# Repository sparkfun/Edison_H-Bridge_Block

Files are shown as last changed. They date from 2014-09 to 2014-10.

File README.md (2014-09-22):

Dual H-bridge
=====================

The Dual H-bridge give the Edison some ability to move when paired with two DC motors.  This board can drive two DC motors at voltages ranging from 2.7V-15V and currents up to 1amp.  This board is isolated from the Edison using a logic level converter.  To use this board external power for the motors will be required.  Power for the motors is supplied on the headers labled "VIN" and "GND"

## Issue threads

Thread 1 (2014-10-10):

TBx0108 max voltage on "B" side... or breaking out "VM" for higher voltages

lewispg228, 2014-10-10:
I think it might be worth noting that the max voltage you can supply on VIN is 5.5V, or else you are going outside the max voltage on the "B" side of the logic conversion chip.

I was working on the testbed for this, and was worried that 5.5V may only light up the LEDs very dimly (a pain to test visually in production). We could think about reducing the values for R1 and R2, or we could think about breaking out VM, to allow for higher voltages to your motors (while still keeping the logic level within the TBX0108 chips specs)

ToniCorinne, 2016-07-19:
Closing out this issue as there do not appear to be any customer complaints about this currently.

Closed 2016-07-19.

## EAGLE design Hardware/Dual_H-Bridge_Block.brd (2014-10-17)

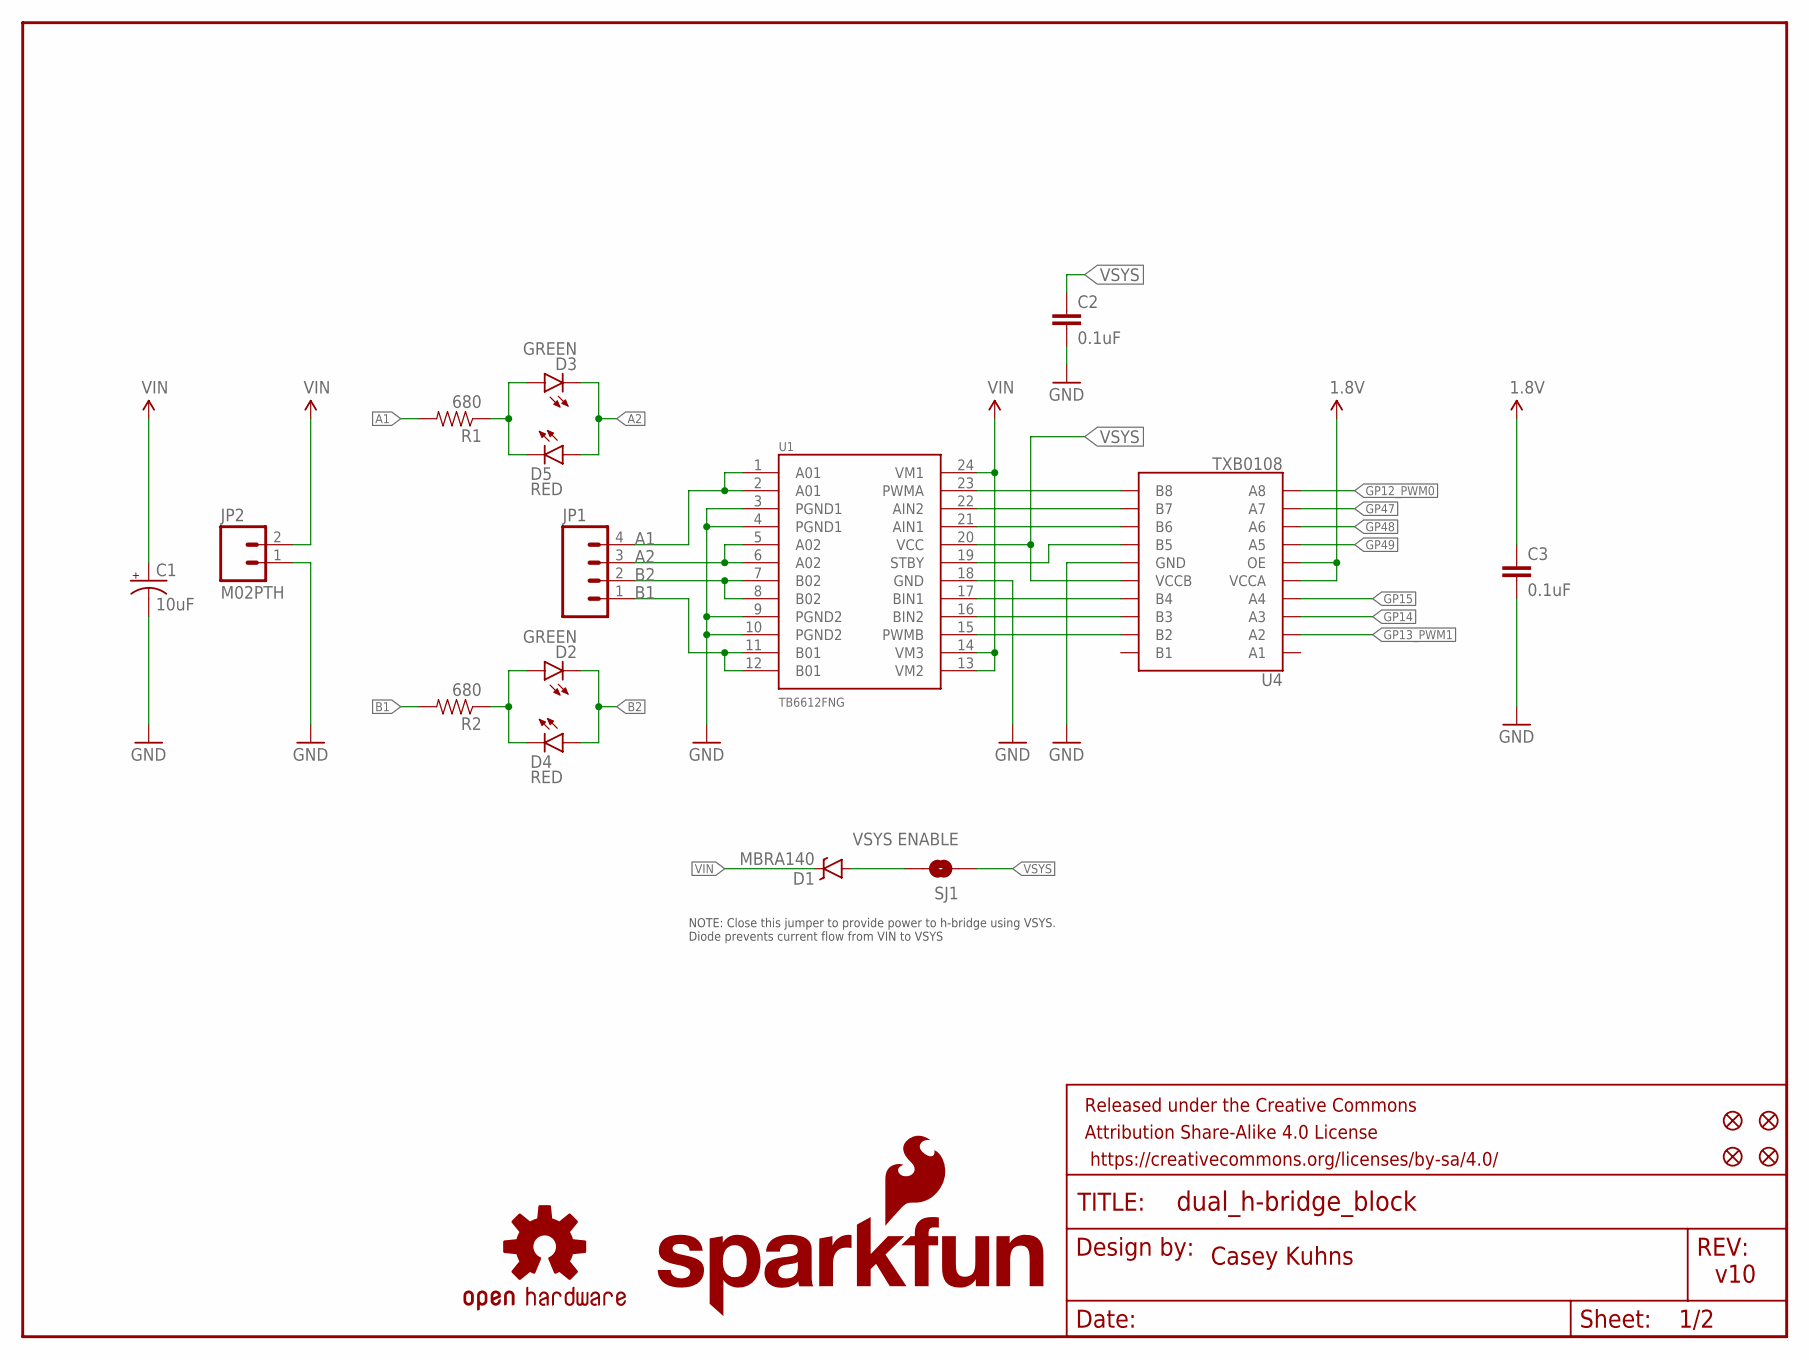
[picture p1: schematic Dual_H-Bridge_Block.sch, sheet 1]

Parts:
C1: 10uF; EIA3216
C2, C3: 0.1uF; 0603-CAP
D1: MBRA140; SMA-DIODE
D2, D3: GREEN; LED-0603
D4, D5: RED; LED-0603
FID1, FID2, FID3, FID4: FIDUCIAL1X2; FIDUCIAL-1X2
FRAME1: FRAME-LETTER; CREATIVE_COMMONS
JP1: M04PTH; 1X04
JP2: M02PTH; 1X02
LOGO1: OSHW-LOGOS; OSHW-LOGO-S
LOGO4: SFE_LOGO_NAME_FLAME.1_INCH; SFE_LOGO_NAME_FLAME_.1
R1, R2: 680; 0603-RES
SJ1: VSYS ENABLE; PAD-JUMPER-2-NO_YES_SILK
U1: TB6612FNG; SSOP24
U4: TXB0108; UFDFN-20

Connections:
1.8V: C3.1, U4.5 (VCCA), U4.6 (OE); also elsewhere on the board
A1: JP1.4, R1.2, U1.1 (A01), U1.2 (A01)
A2: D3.C, D5.A, JP1.3, U1.5 (A02), U1.6 (A02)
B1: JP1.1, R2.2, U1.11 (B01), U1.12 (B01)
B2: D2.C, D4.A, JP1.2, U1.7 (B02), U1.8 (B02)
GND: C1.C (-), C2.2, C3.2, JP2.1, U1.3 (PGND1), U1.4 (PGND1), U1.9 (PGND2), U1.10 (PGND2), U1.18 (GND), U4.15 (GND); also elsewhere on the board
GP12_PWM0: U4.10 (A8); also elsewhere on the board
GP13_PWM1: U4.2 (A2); also elsewhere on the board
GP14: U4.3 (A3); also elsewhere on the board
GP15: U4.4 (A4); also elsewhere on the board
GP47: U4.9 (A7); also elsewhere on the board
GP48: U4.8 (A6); also elsewhere on the board
GP49: U4.7 (A5); also elsewhere on the board
unnamed: D1.A, SJ1.2
unnamed: D2.A, D4.C, R2.1
unnamed: U1.15 (PWMB), U4.19 (B2)
unnamed: U1.23 (PWMA), U4.11 (B8)
unnamed: D3.A, D5.C, R1.1
unnamed: U1.19 (STBY), U4.14 (B5)
unnamed: U1.17 (BIN1), U4.17 (B4)
unnamed: U1.16 (BIN2), U4.18 (B3)
unnamed: U1.21 (AIN1), U4.13 (B6)
unnamed: U1.22 (AIN2), U4.12 (B7)
VIN: C1.A (+), D1.C, JP2.2, U1.13 (VM2), U1.14 (VM3), U1.24 (VM1)
VSYS: C2.1, SJ1.1, U1.20 (VCC), U4.16 (VCCB); also elsewhere on the board

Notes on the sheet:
v10
Casey Kuhns
NOTE: Close this jumper to provide power to h-bridge using VSYS. Diode prevents current flow from VIN to VSYS

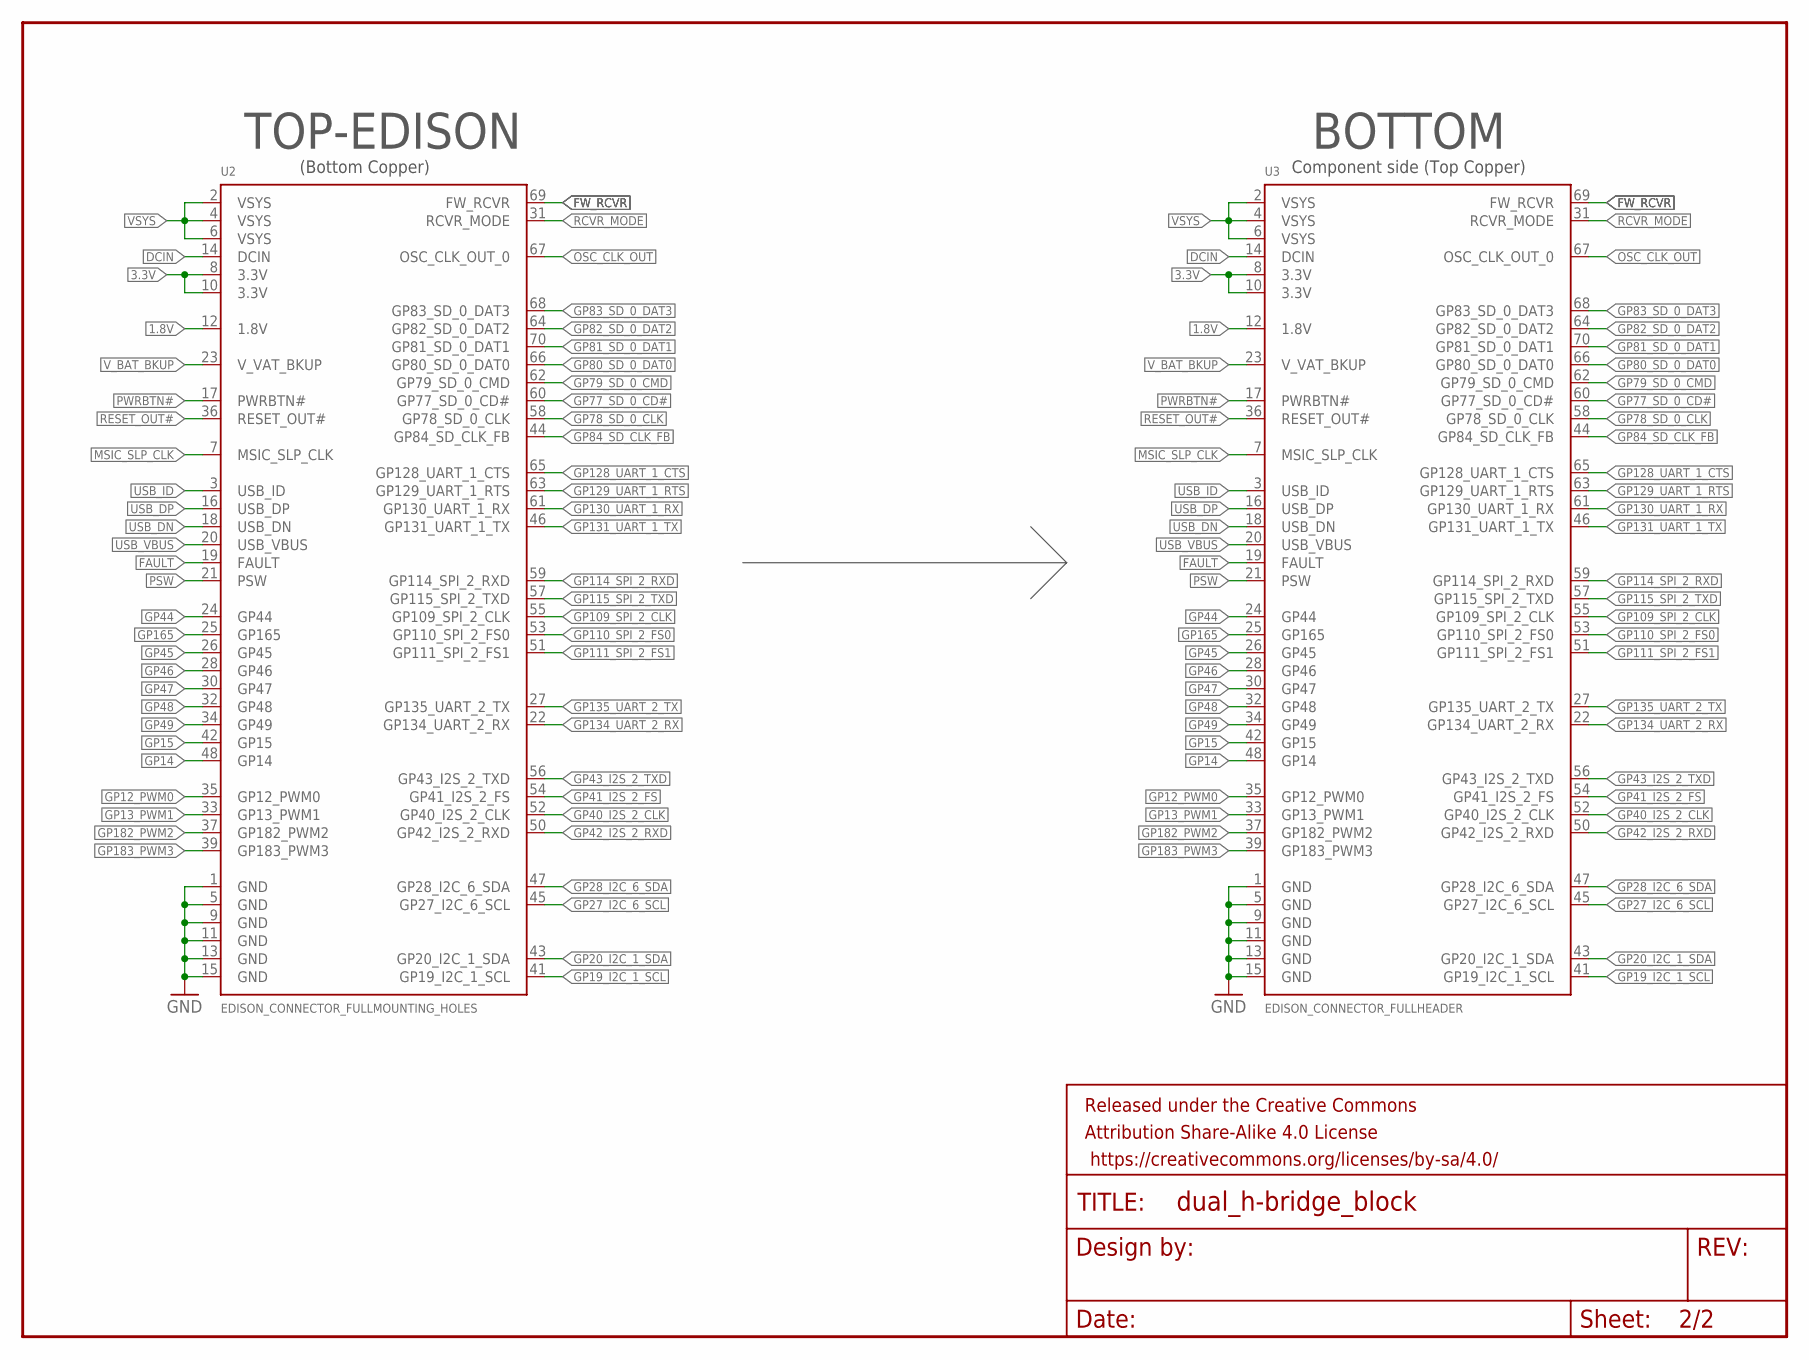
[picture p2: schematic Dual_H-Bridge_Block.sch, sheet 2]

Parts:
FRAME2: FRAME-LETTER; CREATIVE_COMMONS
U2: EDISON_CONNECTOR_FULLMOUNTING_HOLES; EDISON_DAUGHTER
U3: EDISON_CONNECTOR_FULLHEADER; DF40C-70DP-0.4(51)

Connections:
1.8V: U2.12 (1.8V), U3.12 (1.8V); also elsewhere on the board
3.3V: U2.8 (3.3V), U2.10 (3.3V), U3.8 (3.3V), U3.10 (3.3V)
DCIN: U2.14 (DCIN), U3.14 (DCIN)
FAULT: U2.19 (FAULT), U3.19 (FAULT)
FW_RCVR: U2.69 (FW_RCVR), U3.69 (FW_RCVR)
GND: U2.1 (GND), U2.5 (GND), U2.9 (GND), U2.11 (GND), U2.13 (GND), U2.15 (GND), U3.1 (GND), U3.5 (GND), U3.9 (GND), U3.11 (GND), U3.13 (GND), U3.15 (GND); also elsewhere on the board
GP12_PWM0: U2.35 (GP12_PWM0), U3.35 (GP12_PWM0); also elsewhere on the board
GP13_PWM1: U2.33 (GP13_PWM1), U3.33 (GP13_PWM1); also elsewhere on the board
GP14: U2.48 (GP14), U3.48 (GP14); also elsewhere on the board
GP15: U2.42 (GP15), U3.42 (GP15); also elsewhere on the board
GP19_I2C_1_SCL: U2.41 (GP19_I2C_1_SCL), U3.41 (GP19_I2C_1_SCL)
GP20_I2C_1_SDA: U2.43 (GP20_I2C_1_SDA), U3.43 (GP20_I2C_1_SDA)
GP27_I2C_6_SCL: U2.45 (GP27_I2C_6_SCL), U3.45 (GP27_I2C_6_SCL)
GP28_I2C_6_SDA: U2.47 (GP28_I2C_6_SDA), U3.47 (GP28_I2C_6_SDA)
GP40_I2S_2_CLK: U2.52 (GP40_I2S_2_CLK), U3.52 (GP40_I2S_2_CLK)
GP41_I2S_2_FS: U2.54 (GP41_I2S_2_FS), U3.54 (GP41_I2S_2_FS)
GP42_I2S_2_RXD: U2.50 (GP42_I2S_2_RXD), U3.50 (GP42_I2S_2_RXD)
GP43_I2S_2_TXD: U2.56 (GP43_I2S_2_TXD), U3.56 (GP43_I2S_2_TXD)
GP44: U2.24 (GP44), U3.24 (GP44)
GP45: U2.26 (GP45), U3.26 (GP45)
GP46: U2.28 (GP46), U3.28 (GP46)
GP47: U2.30 (GP47), U3.30 (GP47); also elsewhere on the board
GP48: U2.32 (GP48), U3.32 (GP48); also elsewhere on the board
GP49: U2.34 (GP49), U3.34 (GP49); also elsewhere on the board
GP77_SD_0_CD#: U2.60 (GP77_SD_0_CD#), U3.60 (GP77_SD_0_CD#)
GP78_SD_0_CLK: U2.58 (GP78_SD_0_CLK), U3.58 (GP78_SD_0_CLK)
GP79_SD_0_CMD: U2.62 (GP79_SD_0_CMD), U3.62 (GP79_SD_0_CMD)
GP80_SD_0_DAT0: U2.66 (GP80_SD_0_DAT0), U3.66 (GP80_SD_0_DAT0)
GP81_SD_0_DAT1: U2.70 (GP81_SD_0_DAT1), U3.70 (GP81_SD_0_DAT1)
GP82_SD_0_DAT2: U2.64 (GP82_SD_0_DAT2), U3.64 (GP82_SD_0_DAT2)
GP83_SD_0_DAT3: U2.68 (GP83_SD_0_DAT3), U3.68 (GP83_SD_0_DAT3)
GP84_SD_CLK_FB: U2.44 (GP84_SD_CLK_FB), U3.44 (GP84_SD_CLK_FB)
GP109_SPI_2_CLK: U2.55 (GP109_SPI_2_CLK), U3.55 (GP109_SPI_2_CLK)
GP110_SPI_2_FS0: U2.53 (GP110_SPI_2_FS0), U3.53 (GP110_SPI_2_FS0)
GP111_SPI_2_FS1: U2.51 (GP111_SPI_2_FS1), U3.51 (GP111_SPI_2_FS1)
GP114_SPI_2_RXD: U2.59 (GP114_SPI_2_RXD), U3.59 (GP114_SPI_2_RXD)
GP115_SPI_2_TXD: U2.57 (GP115_SPI_2_TXD), U3.57 (GP115_SPI_2_TXD)
GP128_UART_1_CTS: U2.65 (GP128_UART_1_CTS), U3.65 (GP128_UART_1_CTS)
GP129_UART_1_RTS: U2.63 (GP129_UART_1_RTS), U3.63 (GP129_UART_1_RTS)
GP130_UART_1_RX: U2.61 (GP130_UART_1_RX), U3.61 (GP130_UART_1_RX)
GP131_UART_1_TX: U2.46 (GP131_UART_1_TX), U3.46 (GP131_UART_1_TX)
GP134_UART_2_RX: U2.22 (GP134_UART_2_RX), U3.22 (GP134_UART_2_RX)
GP135_UART_2_TX: U2.27 (GP135_UART_2_TX), U3.27 (GP135_UART_2_TX)
GP165: U2.25 (GP165), U3.25 (GP165)
GP182_PWM2: U2.37 (GP182_PWM2), U3.37 (GP182_PWM2)
GP183_PWM3: U2.39 (GP183_PWM3), U3.39 (GP183_PWM3)
MSIC_SLP_CLK: U2.7 (MSIC_SLP_CLK), U3.7 (MSIC_SLP_CLK)
OSC_CLK_OUT: U2.67 (OSC_CLK_OUT_0), U3.67 (OSC_CLK_OUT_0)
PSW: U2.21 (PSW), U3.21 (PSW)
PWRBTN#: U2.17 (PWRBTN#), U3.17 (PWRBTN#)
RCVR_MODE: U2.31 (RCVR_MODE), U3.31 (RCVR_MODE)
RESET_OUT#: U2.36 (RESET_OUT#), U3.36 (RESET_OUT#)
USB_DN: U2.18 (USB_DN), U3.18 (USB_DN)
USB_DP: U2.16 (USB_DP), U3.16 (USB_DP)
USB_ID: U2.3 (USB_ID), U3.3 (USB_ID)
USB_VBUS: U2.20 (USB_VBUS), U3.20 (USB_VBUS)
VSYS: U2.2 (VSYS), U2.4 (VSYS), U2.6 (VSYS), U3.2 (VSYS), U3.4 (VSYS), U3.6 (VSYS); also elsewhere on the board
V_BAT_BKUP: U2.23 (V_VAT_BKUP), U3.23 (V_VAT_BKUP)

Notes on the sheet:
TOP-EDISON
BOTTOM
Component side (Top Copper)
(Bottom Copper)

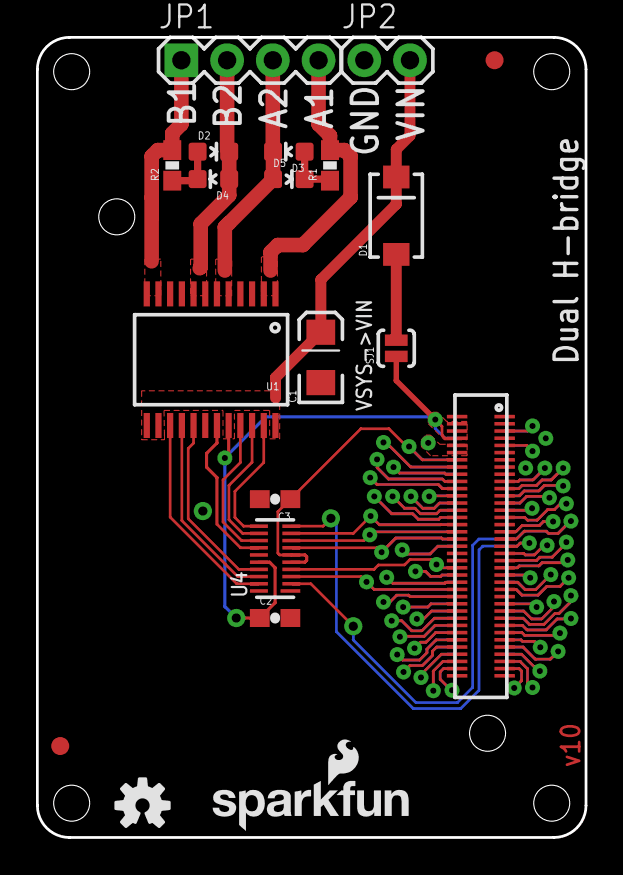
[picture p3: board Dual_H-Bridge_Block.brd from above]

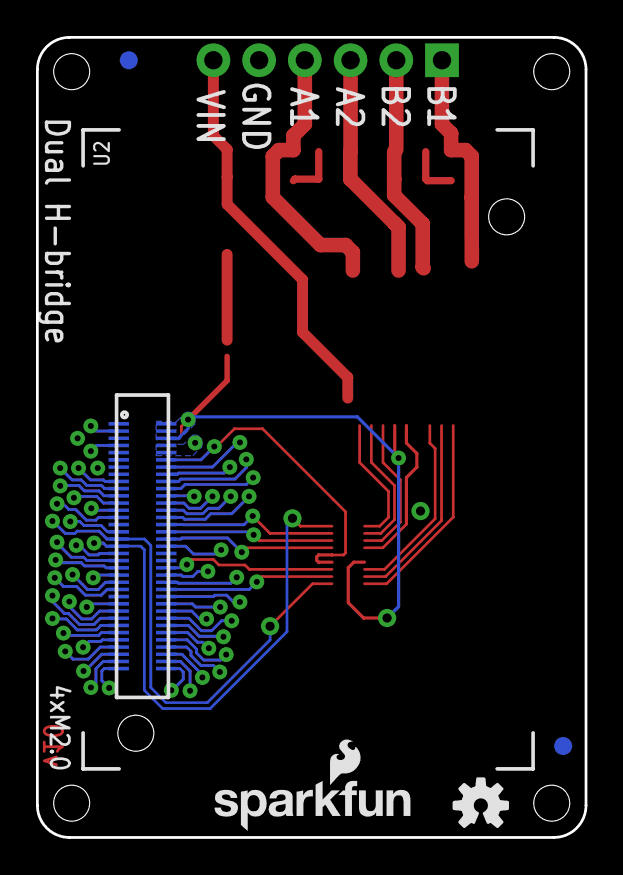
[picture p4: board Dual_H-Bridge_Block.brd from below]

Board: 2 copper layers, 30.5 x 44.5 mm, 27 parts (6 on the bottom side), 73 nets.

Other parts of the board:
LOGO2: OSHW-LOGOS; OSHW-LOGO-S
LOGO3: SFE_LOGO_NAME_FLAME.1_INCH; SFE_LOGO_NAME_FLAME_.1

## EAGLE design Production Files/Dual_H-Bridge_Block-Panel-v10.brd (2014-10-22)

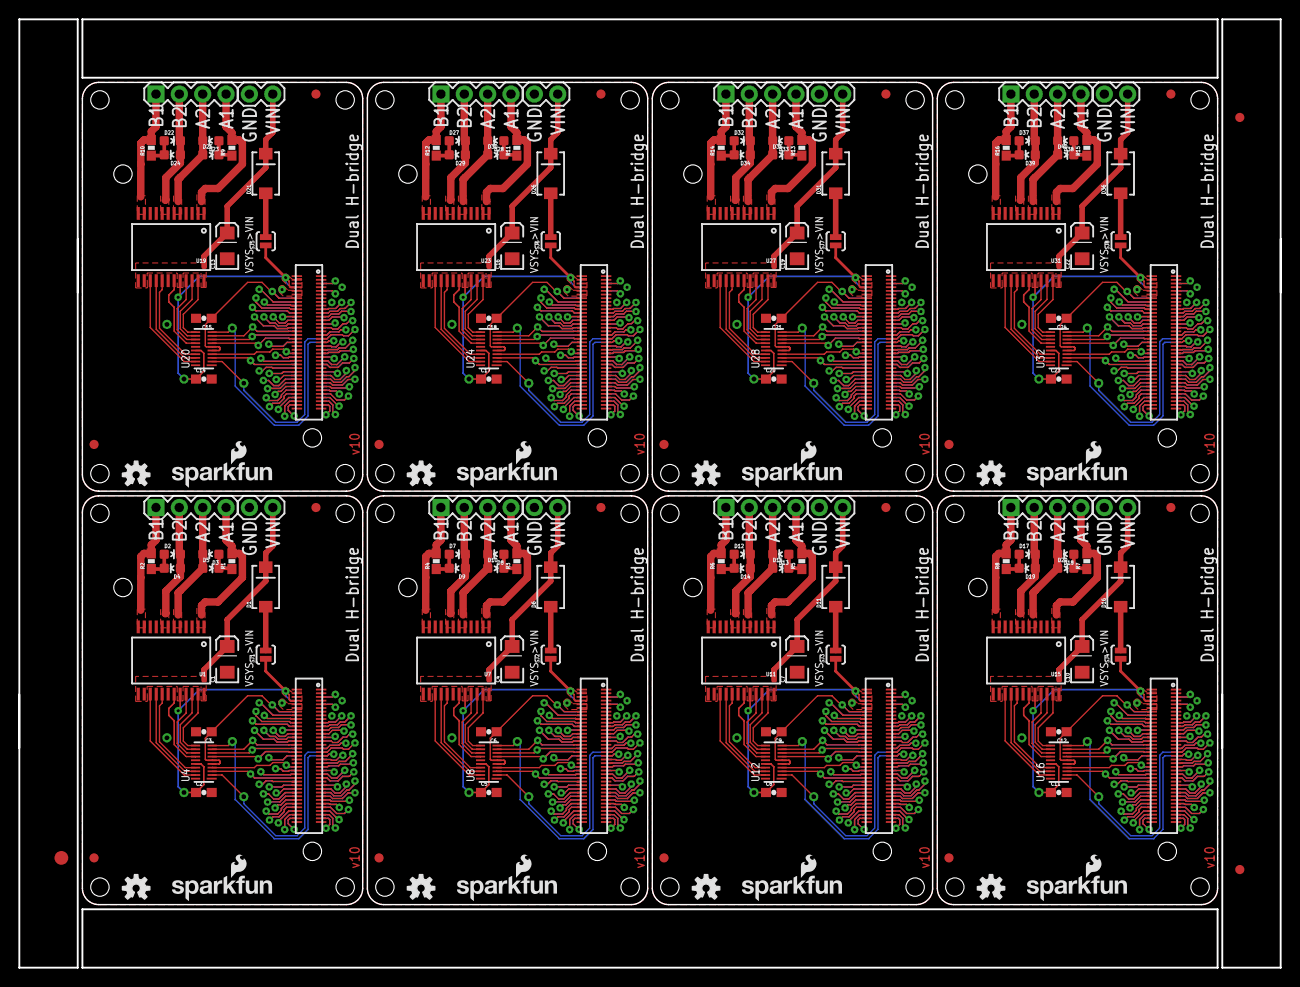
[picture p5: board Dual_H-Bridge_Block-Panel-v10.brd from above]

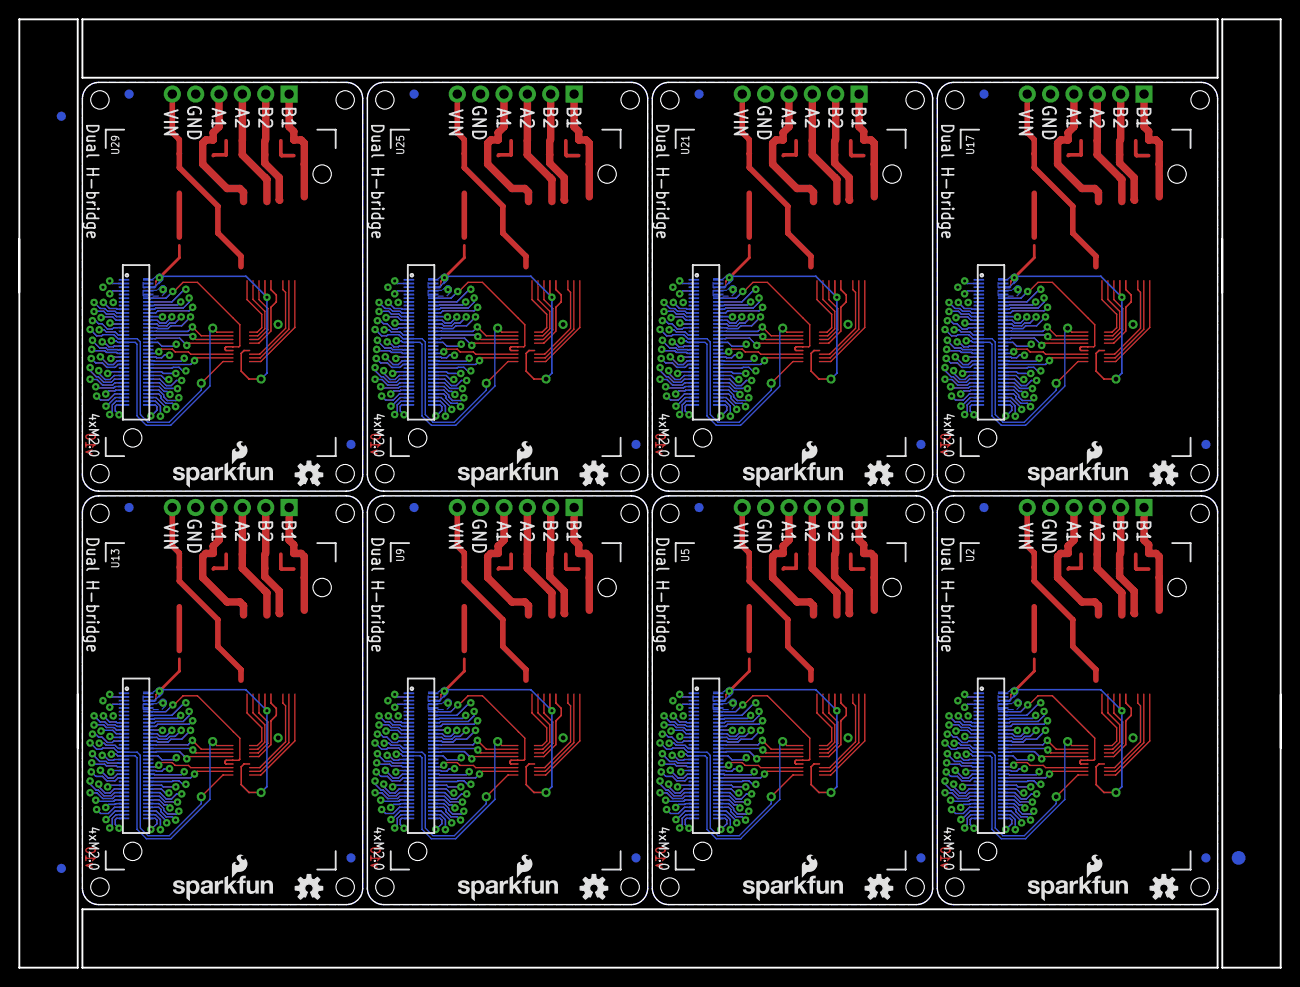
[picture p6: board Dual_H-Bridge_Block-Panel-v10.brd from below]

Board: 2 copper layers, 137.2 x 103.1 mm, 206 parts (51 on the bottom side), 584 nets.

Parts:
C1, C4, C7, C10, C13, C16, C19, C22: 10uF; EIA3216
C2, C3, C5, C6, C8, C9, C11, C12, C14, C15, C17, C18, C20, C21, C23, C24: 0.1uF; 0603-CAP
D1, D6, D11, D16, D21, D26, D31, D36: MBRA140; SMA-DIODE
D2, D3, D7, D8, D12, D13, D17, D18, D22, D23, D27, D28, D32, D33, D37, D38: GREEN; LED-0603
D4, D5, D9, D10, D14, D15, D19, D20, D24, D25, D29, D30, D34, D35, D39, D40: RED; LED-0603
E$1, E$2: FIDUCIAL-1.5X3
E$3, E$4, E$5, E$6: FIDUCIAL-1X2
FID1, FID2, FID3, FID4, FID5, FID6, FID7, FID8, FID9, FID10, FID11, FID12, FID13, FID14, FID15, FID16, FID17, FID18, FID19, FID20, FID21, FID22, FID23, FID24, FID25, FID26, FID27, FID28, FID29, FID30, FID31, FID32: FIDUCIAL1X2; FIDUCIAL-1X2
JP1, JP3, JP5, JP7, JP9, JP11, JP13, JP15: 1X04
JP2, JP4, JP6, JP8, JP10, JP12, JP14, JP16: M02PTH; 1X02
LOGO1, LOGO2, LOGO5, LOGO7, LOGO9, LOGO11, LOGO13, LOGO15, LOGO17, LOGO19, LOGO21, LOGO23, LOGO25, LOGO27, LOGO29, LOGO31: OSHW-LOGOS; OSHW-LOGO-S
LOGO3, LOGO4, LOGO6, LOGO8, LOGO10, LOGO12, LOGO14, LOGO16, LOGO18, LOGO20, LOGO22, LOGO24, LOGO26, LOGO28, LOGO30, LOGO32: SFE_LOGO_NAME_FLAME.1_INCH; SFE_LOGO_NAME_FLAME_.1
R1, R2, R3, R4, R5, R6, R7, R8, R9, R10, R11, R12, R13, R14, R15, R16: 680; 0603-RES
SJ1, SJ2, SJ3, SJ4, SJ5, SJ6, SJ7, SJ8: VSYS ENABLE; PAD-JUMPER-2-NO_YES_SILK
U1, U7, U11, U15, U19, U23, U27, U31: TB6612FNG; SSOP24
U2, U5, U9, U13, U17, U21, U25, U29: EDISON_CONNECTOR_FULLMOUNTING_HOLES; EDISON_DAUGHTER
U3, U6, U10, U14, U18, U22, U26, U30: EDISON_CONNECTOR_FULLHEADER; DF40C-70DP-0.4(51)
U4, U8, U12, U16, U20, U24, U28, U32: TXB0108; UFDFN-20

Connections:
1.8V: C3.1, U2.12, U3.12, U4.5, U4.6
1.8V1: C6.1, U5.12, U6.12, U8.5, U8.6
1.8V2: C9.1, U9.12, U10.12, U12.5, U12.6
1.8V3: C12.1, U13.12, U14.12, U16.5, U16.6
1.8V4: C15.1, U17.12, U18.12, U20.5, U20.6
1.8V5: C18.1, U21.12, U22.12, U24.5, U24.6
1.8V6: C21.1, U25.12, U26.12, U28.5, U28.6
1.8V7: C24.1, U29.12, U30.12, U32.5, U32.6
3.3V: U2.8, U2.10, U3.8, U3.10
3.3V1: U5.8, U5.10, U6.8, U6.10
3.3V2: U9.8, U9.10, U10.8, U10.10
3.3V3: U13.8, U13.10, U14.8, U14.10
3.3V4: U17.8, U17.10, U18.8, U18.10
3.3V5: U21.8, U21.10, U22.8, U22.10
3.3V6: U25.8, U25.10, U26.8, U26.10
3.3V7: U29.8, U29.10, U30.8, U30.10
A1: JP1.4, R1.2, U1.1, U1.2
A2: D3.C, D5.A, JP1.3, U1.5, U1.6
A3: D8.C, D10.A, JP3.3, U7.5, U7.6
A4: JP3.4, R3.2, U7.1, U7.2
A5: D13.C, D15.A, JP5.3, U11.5, U11.6
A6: JP5.4, R5.2, U11.1, U11.2
A7: D18.C, D20.A, JP7.3, U15.5, U15.6
A8: JP7.4, R7.2, U15.1, U15.2
A9: D23.C, D25.A, JP9.3, U19.5, U19.6
A10: JP9.4, R9.2, U19.1, U19.2
A11: D28.C, D30.A, JP11.3, U23.5, U23.6
A12: JP11.4, R11.2, U23.1, U23.2
A13: D33.C, D35.A, JP13.3, U27.5, U27.6
A14: JP13.4, R13.2, U27.1, U27.2
A15: D38.C, D40.A, JP15.3, U31.5, U31.6
A16: JP15.4, R15.2, U31.1, U31.2
B1: JP1.1, R2.2, U1.11, U1.12
B2: D2.C, D4.A, JP1.2, U1.7, U1.8
B3: JP3.1, R4.2, U7.11, U7.12
B4: D7.C, D9.A, JP3.2, U7.7, U7.8
B5: JP5.1, R6.2, U11.11, U11.12
B6: D12.C, D14.A, JP5.2, U11.7, U11.8
B7: JP7.1, R8.2, U15.11, U15.12
B8: D17.C, D19.A, JP7.2, U15.7, U15.8
B9: JP9.1, R10.2, U19.11, U19.12
B10: D22.C, D24.A, JP9.2, U19.7, U19.8
B11: JP11.1, R12.2, U23.11, U23.12
B12: D27.C, D29.A, JP11.2, U23.7, U23.8
B13: JP13.1, R14.2, U27.11, U27.12
B14: D32.C, D34.A, JP13.2, U27.7, U27.8
B15: JP15.1, R16.2, U31.11, U31.12
B16: D37.C, D39.A, JP15.2, U31.7, U31.8
DCIN: U2.14, U3.14
DCIN1: U5.14, U6.14
DCIN2: U9.14, U10.14
DCIN3: U13.14, U14.14
DCIN4: U17.14, U18.14
DCIN5: U21.14, U22.14
DCIN6: U25.14, U26.14
DCIN7: U29.14, U30.14
FAULT: U2.19, U3.19
FAULT1: U5.19, U6.19
FAULT2: U9.19, U10.19
FAULT3: U13.19, U14.19
FAULT4: U17.19, U18.19
FAULT5: U21.19, U22.19
FAULT6: U25.19, U26.19
FAULT7: U29.19, U30.19
FW_RCVR: U2.69, U3.69
FW_RCVR1: U5.69, U6.69
FW_RCVR2: U9.69, U10.69
FW_RCVR3: U13.69, U14.69
FW_RCVR4: U17.69, U18.69
FW_RCVR5: U21.69, U22.69
FW_RCVR6: U25.69, U26.69
FW_RCVR7: U29.69, U30.69
GND: C1.C, C2.2, C3.2, JP2.1, U1.3, U1.4, U1.9, U1.10, U1.18, U2.1, U2.5, U2.9, U2.11, U2.13, U2.15, U3.1, U3.5, U3.9, U3.11, U3.13, U3.15, U4.15
GND1: C4.C, C5.2, C6.2, JP4.1, U5.1, U5.5, U5.9, U5.11, U5.13, U5.15, U6.1, U6.5, U6.9, U6.11, U6.13, U6.15, U7.3, U7.4, U7.9, U7.10, U7.18, U8.15
GND2: C7.C, C8.2, C9.2, JP6.1, U9.1, U9.5, U9.9, U9.11, U9.13, U9.15, U10.1, U10.5, U10.9, U10.11, U10.13, U10.15, U11.3, U11.4, U11.9, U11.10, U11.18, U12.15
GND3: C10.C, C11.2, C12.2, JP8.1, U13.1, U13.5, U13.9, U13.11, U13.13, U13.15, U14.1, U14.5, U14.9, U14.11, U14.13, U14.15, U15.3, U15.4, U15.9, U15.10, U15.18, U16.15
GND4: C13.C, C14.2, C15.2, JP10.1, U17.1, U17.5, U17.9, U17.11, U17.13, U17.15, U18.1, U18.5, U18.9, U18.11, U18.13, U18.15, U19.3, U19.4, U19.9, U19.10, U19.18, U20.15
GND5: C16.C, C17.2, C18.2, JP12.1, U21.1, U21.5, U21.9, U21.11, U21.13, U21.15, U22.1, U22.5, U22.9, U22.11, U22.13, U22.15, U23.3, U23.4, U23.9, U23.10, U23.18, U24.15
GND6: C19.C, C20.2, C21.2, JP14.1, U25.1, U25.5, U25.9, U25.11, U25.13, U25.15, U26.1, U26.5, U26.9, U26.11, U26.13, U26.15, U27.3, U27.4, U27.9, U27.10, U27.18, U28.15
GND7: C22.C, C23.2, C24.2, JP16.1, U29.1, U29.5, U29.9, U29.11, U29.13, U29.15, U30.1, U30.5, U30.9, U30.11, U30.13, U30.15, U31.3, U31.4, U31.9, U31.10, U31.18, U32.15
GP1: U5.48, U6.48, U8.3
GP2: U5.42, U6.42, U8.4
GP3: U5.34, U6.34, U8.7
GP4: U5.32, U6.32, U8.8
GP5: U5.30, U6.30, U8.9
GP6: U5.28, U6.28
GP7: U5.26, U6.26
GP8: U5.25, U6.25
GP9: U5.24, U6.24
GP10: U9.48, U10.48, U12.3
GP11: U9.42, U10.42, U12.4
GP12: U9.34, U10.34, U12.7
GP12_PWM0: U2.35, U3.35, U4.10
GP12_PWM1: U5.35, U6.35, U8.10
GP12_PWM2: U9.35, U10.35, U12.10
GP12_PWM3: U13.35, U14.35, U16.10
GP12_PWM4: U17.35, U18.35, U20.10
GP12_PWM5: U21.35, U22.35, U24.10
GP12_PWM6: U25.35, U26.35, U28.10
GP12_PWM7: U29.35, U30.35, U32.10
GP13: U9.32, U10.32, U12.8
GP13_PWM1: U2.33, U3.33, U4.2
GP13_PWM2: U5.33, U6.33, U8.2
GP13_PWM3: U9.33, U10.33, U12.2
GP13_PWM4: U13.33, U14.33, U16.2
GP13_PWM5: U17.33, U18.33, U20.2
GP13_PWM6: U21.33, U22.33, U24.2
GP13_PWM7: U25.33, U26.33, U28.2
GP13_PWM8: U29.33, U30.33, U32.2
GP14: U2.48, U3.48, U4.3
GP15: U2.42, U3.42, U4.4
GP16: U9.30, U10.30, U12.9
GP17: U9.28, U10.28
GP18: U9.26, U10.26
GP19: U9.25, U10.25
GP19_I2C_1_SCL: U2.41, U3.41
GP19_I2C_1_SCL1: U5.41, U6.41
GP19_I2C_1_SCL2: U9.41, U10.41
GP19_I2C_1_SCL3: U13.41, U14.41
GP19_I2C_1_SCL4: U17.41, U18.41
GP19_I2C_1_SCL5: U21.41, U22.41
GP19_I2C_1_SCL6: U25.41, U26.41
GP19_I2C_1_SCL7: U29.41, U30.41
GP20: U9.24, U10.24
GP20_I2C_1_SDA: U2.43, U3.43
GP20_I2C_1_SDA1: U5.43, U6.43
GP20_I2C_1_SDA2: U9.43, U10.43
GP20_I2C_1_SDA3: U13.43, U14.43
GP20_I2C_1_SDA4: U17.43, U18.43
GP20_I2C_1_SDA5: U21.43, U22.43
GP20_I2C_1_SDA6: U25.43, U26.43
GP20_I2C_1_SDA7: U29.43, U30.43
GP21: U13.48, U14.48, U16.3
GP22: U13.42, U14.42, U16.4
GP23: U13.34, U14.34, U16.7
GP24: U13.32, U14.32, U16.8
GP25: U13.30, U14.30, U16.9
GP26: U13.28, U14.28
GP27: U13.26, U14.26
GP27_I2C_6_SCL: U2.45, U3.45
GP27_I2C_6_SCL1: U5.45, U6.45
GP27_I2C_6_SCL2: U9.45, U10.45
GP27_I2C_6_SCL3: U13.45, U14.45
GP27_I2C_6_SCL4: U17.45, U18.45
GP27_I2C_6_SCL5: U21.45, U22.45
GP27_I2C_6_SCL6: U25.45, U26.45
GP27_I2C_6_SCL7: U29.45, U30.45
GP28: U13.25, U14.25
GP28_I2C_6_SDA: U2.47, U3.47
GP28_I2C_6_SDA1: U5.47, U6.47
GP28_I2C_6_SDA2: U9.47, U10.47
GP28_I2C_6_SDA3: U13.47, U14.47
GP28_I2C_6_SDA4: U17.47, U18.47
GP28_I2C_6_SDA5: U21.47, U22.47
GP28_I2C_6_SDA6: U25.47, U26.47
GP28_I2C_6_SDA7: U29.47, U30.47
GP29: U13.24, U14.24
GP30: U17.48, U18.48, U20.3
GP31: U17.42, U18.42, U20.4
GP32: U17.34, U18.34, U20.7
GP33: U17.32, U18.32, U20.8
GP34: U17.30, U18.30, U20.9
GP35: U17.28, U18.28
GP36: U17.26, U18.26
GP37: U17.25, U18.25
GP38: U17.24, U18.24
GP39: U21.48, U22.48, U24.3
GP40: U21.42, U22.42, U24.4
GP40_I2S_2_CLK: U2.52, U3.52
GP40_I2S_2_CLK1: U5.52, U6.52
GP40_I2S_2_CLK2: U9.52, U10.52
GP40_I2S_2_CLK3: U13.52, U14.52
GP40_I2S_2_CLK4: U17.52, U18.52
GP40_I2S_2_CLK5: U21.52, U22.52
GP40_I2S_2_CLK6: U25.52, U26.52
GP40_I2S_2_CLK7: U29.52, U30.52
GP41: U21.34, U22.34, U24.7
GP41_I2S_2_FS: U2.54, U3.54
GP41_I2S_2_FS1: U5.54, U6.54
GP41_I2S_2_FS2: U9.54, U10.54
GP41_I2S_2_FS3: U13.54, U14.54
GP41_I2S_2_FS4: U17.54, U18.54
GP41_I2S_2_FS5: U21.54, U22.54
GP41_I2S_2_FS6: U25.54, U26.54
GP41_I2S_2_FS7: U29.54, U30.54
GP42: U21.32, U22.32, U24.8
GP42_I2S_2_RXD: U2.50, U3.50
GP42_I2S_2_RXD1: U5.50, U6.50
GP42_I2S_2_RXD2: U9.50, U10.50
GP42_I2S_2_RXD3: U13.50, U14.50
GP42_I2S_2_RXD4: U17.50, U18.50
GP42_I2S_2_RXD5: U21.50, U22.50
GP42_I2S_2_RXD6: U25.50, U26.50
GP42_I2S_2_RXD7: U29.50, U30.50
GP43: U21.30, U22.30, U24.9
GP43_I2S_2_TXD: U2.56, U3.56
GP43_I2S_2_TXD1: U5.56, U6.56
GP43_I2S_2_TXD2: U9.56, U10.56
GP43_I2S_2_TXD3: U13.56, U14.56
GP43_I2S_2_TXD4: U17.56, U18.56
GP43_I2S_2_TXD5: U21.56, U22.56
GP43_I2S_2_TXD6: U25.56, U26.56
GP43_I2S_2_TXD7: U29.56, U30.56
GP44: U2.24, U3.24
GP45: U2.26, U3.26
GP46: U2.28, U3.28
GP47: U2.30, U3.30, U4.9
GP48: U2.32, U3.32, U4.8
GP49: U2.34, U3.34, U4.7
GP50: U21.28, U22.28
GP51: U21.26, U22.26
GP52: U21.25, U22.25
GP53: U21.24, U22.24
GP54: U25.48, U26.48, U28.3
GP55: U25.42, U26.42, U28.4
GP56: U25.34, U26.34, U28.7
GP57: U25.32, U26.32, U28.8
GP58: U25.30, U26.30, U28.9
GP59: U25.28, U26.28
GP60: U25.26, U26.26
GP61: U25.25, U26.25
GP62: U25.24, U26.24
GP63: U29.48, U30.48, U32.3
GP64: U29.42, U30.42, U32.4
GP65: U29.34, U30.34, U32.7
GP66: U29.32, U30.32, U32.8
GP67: U29.30, U30.30, U32.9
GP68: U29.28, U30.28
GP69: U29.26, U30.26
GP70: U29.25, U30.25
GP71: U29.24, U30.24
GP77_SD_0_CD#: U2.60, U3.60
GP77_SD_0_CD#1: U5.60, U6.60
GP77_SD_0_CD#2: U9.60, U10.60
GP77_SD_0_CD#3: U13.60, U14.60
GP77_SD_0_CD#4: U17.60, U18.60
GP77_SD_0_CD#5: U21.60, U22.60
GP77_SD_0_CD#6: U25.60, U26.60
GP77_SD_0_CD#7: U29.60, U30.60
GP78_SD_0_CLK: U2.58, U3.58
GP78_SD_0_CLK1: U5.58, U6.58
GP78_SD_0_CLK2: U9.58, U10.58
GP78_SD_0_CLK3: U13.58, U14.58
GP78_SD_0_CLK4: U17.58, U18.58
GP78_SD_0_CLK5: U21.58, U22.58
GP78_SD_0_CLK6: U25.58, U26.58
GP78_SD_0_CLK7: U29.58, U30.58
GP79_SD_0_CMD: U2.62, U3.62
GP79_SD_0_CMD1: U5.62, U6.62
GP79_SD_0_CMD2: U9.62, U10.62
GP79_SD_0_CMD3: U13.62, U14.62
GP79_SD_0_CMD4: U17.62, U18.62
GP79_SD_0_CMD5: U21.62, U22.62
GP79_SD_0_CMD6: U25.62, U26.62
GP79_SD_0_CMD7: U29.62, U30.62
GP80_SD_0_DAT0: U2.66, U3.66
GP80_SD_0_DAT1: U5.66, U6.66
GP80_SD_0_DAT2: U9.66, U10.66
GP80_SD_0_DAT3: U13.66, U14.66
GP80_SD_0_DAT4: U17.66, U18.66
GP80_SD_0_DAT5: U21.66, U22.66
GP80_SD_0_DAT6: U25.66, U26.66
GP80_SD_0_DAT7: U29.66, U30.66
GP81_SD_0_DAT1: U2.70, U3.70
GP81_SD_0_DAT2: U5.70, U6.70
GP81_SD_0_DAT3: U9.70, U10.70
GP81_SD_0_DAT4: U13.70, U14.70
GP81_SD_0_DAT5: U17.70, U18.70
GP81_SD_0_DAT6: U21.70, U22.70
GP81_SD_0_DAT7: U25.70, U26.70
GP81_SD_0_DAT8: U29.70, U30.70
GP82_SD_0_DAT1: U5.64, U6.64
GP82_SD_0_DAT2: U2.64, U3.64
GP82_SD_0_DAT3: U9.64, U10.64
GP82_SD_0_DAT4: U13.64, U14.64
GP82_SD_0_DAT5: U17.64, U18.64
GP82_SD_0_DAT6: U21.64, U22.64
GP82_SD_0_DAT7: U25.64, U26.64
GP82_SD_0_DAT8: U29.64, U30.64
GP83_SD_0_DAT1: U5.68, U6.68
GP83_SD_0_DAT2: U9.68, U10.68
GP83_SD_0_DAT3: U2.68, U3.68
GP83_SD_0_DAT4: U13.68, U14.68
GP83_SD_0_DAT5: U17.68, U18.68
GP83_SD_0_DAT6: U21.68, U22.68
GP83_SD_0_DAT7: U25.68, U26.68
GP83_SD_0_DAT8: U29.68, U30.68
GP84_SD_CLK_FB: U2.44, U3.44
GP84_SD_CLK_FB1: U5.44, U6.44
GP84_SD_CLK_FB2: U9.44, U10.44
GP84_SD_CLK_FB3: U13.44, U14.44
GP84_SD_CLK_FB4: U17.44, U18.44
GP84_SD_CLK_FB5: U21.44, U22.44
GP84_SD_CLK_FB6: U25.44, U26.44
GP84_SD_CLK_FB7: U29.44, U30.44
GP109_SPI_2_CLK: U2.55, U3.55
GP109_SPI_2_CLK1: U5.55, U6.55
GP109_SPI_2_CLK2: U9.55, U10.55
GP109_SPI_2_CLK3: U13.55, U14.55
GP109_SPI_2_CLK4: U17.55, U18.55
GP109_SPI_2_CLK5: U21.55, U22.55
GP109_SPI_2_CLK6: U25.55, U26.55
GP109_SPI_2_CLK7: U29.55, U30.55
GP110_SPI_2_FS0: U2.53, U3.53
GP110_SPI_2_FS1: U5.53, U6.53
GP110_SPI_2_FS2: U9.53, U10.53
GP110_SPI_2_FS3: U13.53, U14.53
GP110_SPI_2_FS4: U17.53, U18.53
GP110_SPI_2_FS5: U21.53, U22.53
GP110_SPI_2_FS6: U25.53, U26.53
GP110_SPI_2_FS7: U29.53, U30.53
GP111_SPI_2_FS1: U2.51, U3.51
GP111_SPI_2_FS2: U5.51, U6.51
GP111_SPI_2_FS3: U9.51, U10.51
GP111_SPI_2_FS4: U13.51, U14.51
GP111_SPI_2_FS5: U17.51, U18.51
GP111_SPI_2_FS6: U21.51, U22.51
GP111_SPI_2_FS7: U25.51, U26.51
GP111_SPI_2_FS8: U29.51, U30.51
GP114_SPI_2_RXD: U2.59, U3.59
GP114_SPI_2_RXD1: U5.59, U6.59
GP114_SPI_2_RXD2: U9.59, U10.59
GP114_SPI_2_RXD3: U13.59, U14.59
GP114_SPI_2_RXD4: U17.59, U18.59
GP114_SPI_2_RXD5: U21.59, U22.59
GP114_SPI_2_RXD6: U25.59, U26.59
GP114_SPI_2_RXD7: U29.59, U30.59
GP115_SPI_2_TXD: U2.57, U3.57
GP115_SPI_2_TXD1: U5.57, U6.57
GP115_SPI_2_TXD2: U9.57, U10.57
GP115_SPI_2_TXD3: U13.57, U14.57
GP115_SPI_2_TXD4: U17.57, U18.57
GP115_SPI_2_TXD5: U21.57, U22.57
GP115_SPI_2_TXD6: U25.57, U26.57
GP115_SPI_2_TXD7: U29.57, U30.57
GP128_UART_1_CTS: U2.65, U3.65
GP128_UART_1_CTS1: U5.65, U6.65
GP128_UART_1_CTS2: U9.65, U10.65
GP128_UART_1_CTS3: U13.65, U14.65
GP128_UART_1_CTS4: U17.65, U18.65
GP128_UART_1_CTS5: U21.65, U22.65
GP128_UART_1_CTS6: U25.65, U26.65
GP128_UART_1_CTS7: U29.65, U30.65
GP129_UART_1_RTS: U2.63, U3.63
GP129_UART_1_RTS1: U5.63, U6.63
GP129_UART_1_RTS2: U9.63, U10.63
GP129_UART_1_RTS3: U13.63, U14.63
GP129_UART_1_RTS4: U17.63, U18.63
GP129_UART_1_RTS5: U21.63, U22.63
GP129_UART_1_RTS6: U25.63, U26.63
GP129_UART_1_RTS7: U29.63, U30.63
GP130_UART_1_RX: U2.61, U3.61
GP130_UART_1_RX1: U5.61, U6.61
GP130_UART_1_RX2: U9.61, U10.61
GP130_UART_1_RX3: U13.61, U14.61
GP130_UART_1_RX4: U17.61, U18.61
GP130_UART_1_RX5: U21.61, U22.61
GP130_UART_1_RX6: U25.61, U26.61
GP130_UART_1_RX7: U29.61, U30.61
GP131_UART_1_TX: U2.46, U3.46
GP131_UART_1_TX1: U5.46, U6.46
GP131_UART_1_TX2: U9.46, U10.46
GP131_UART_1_TX3: U13.46, U14.46
GP131_UART_1_TX4: U17.46, U18.46
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

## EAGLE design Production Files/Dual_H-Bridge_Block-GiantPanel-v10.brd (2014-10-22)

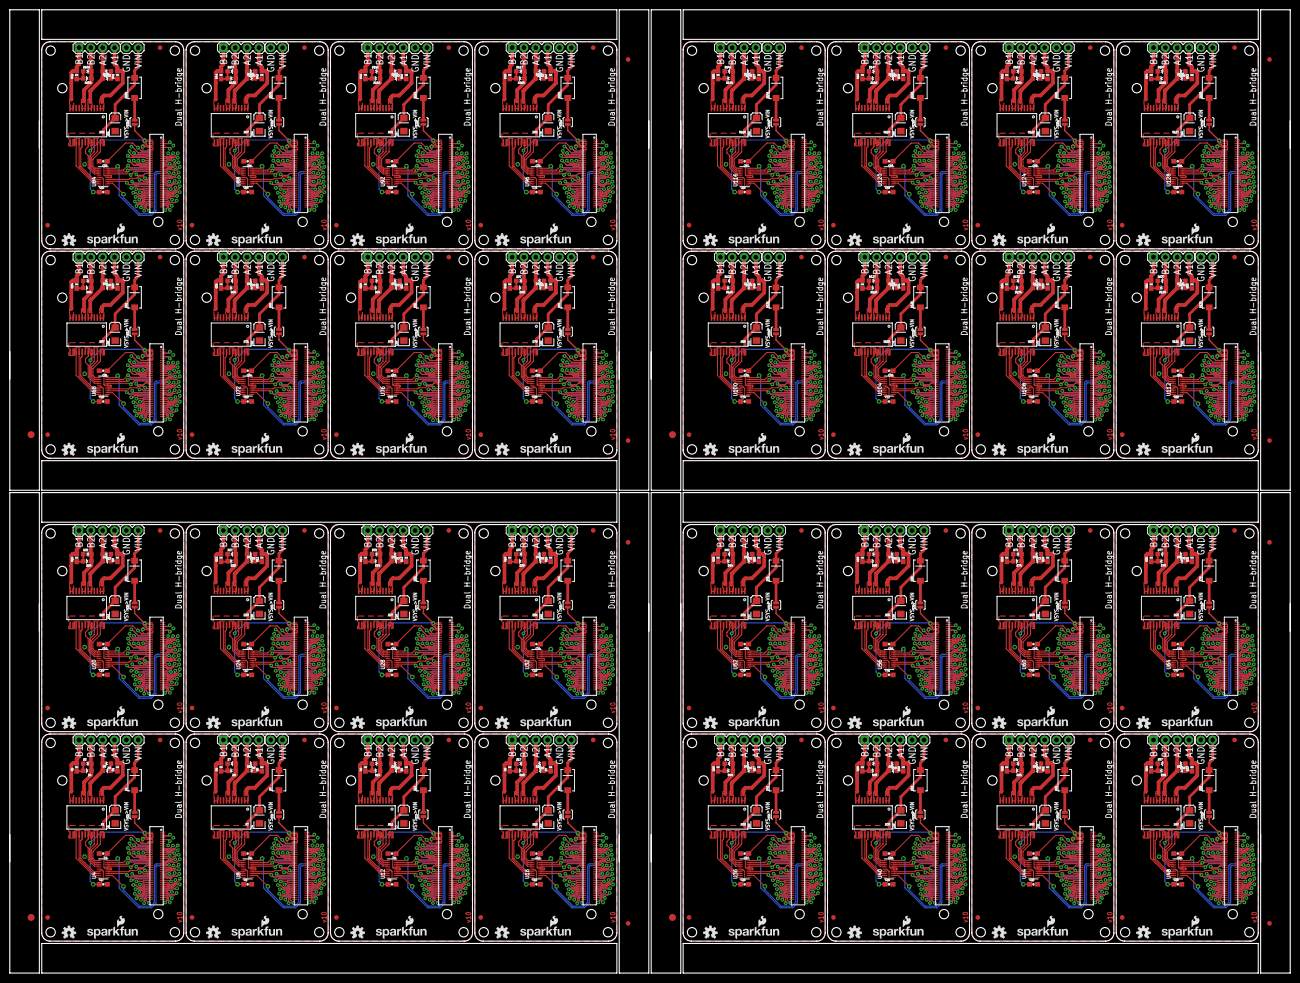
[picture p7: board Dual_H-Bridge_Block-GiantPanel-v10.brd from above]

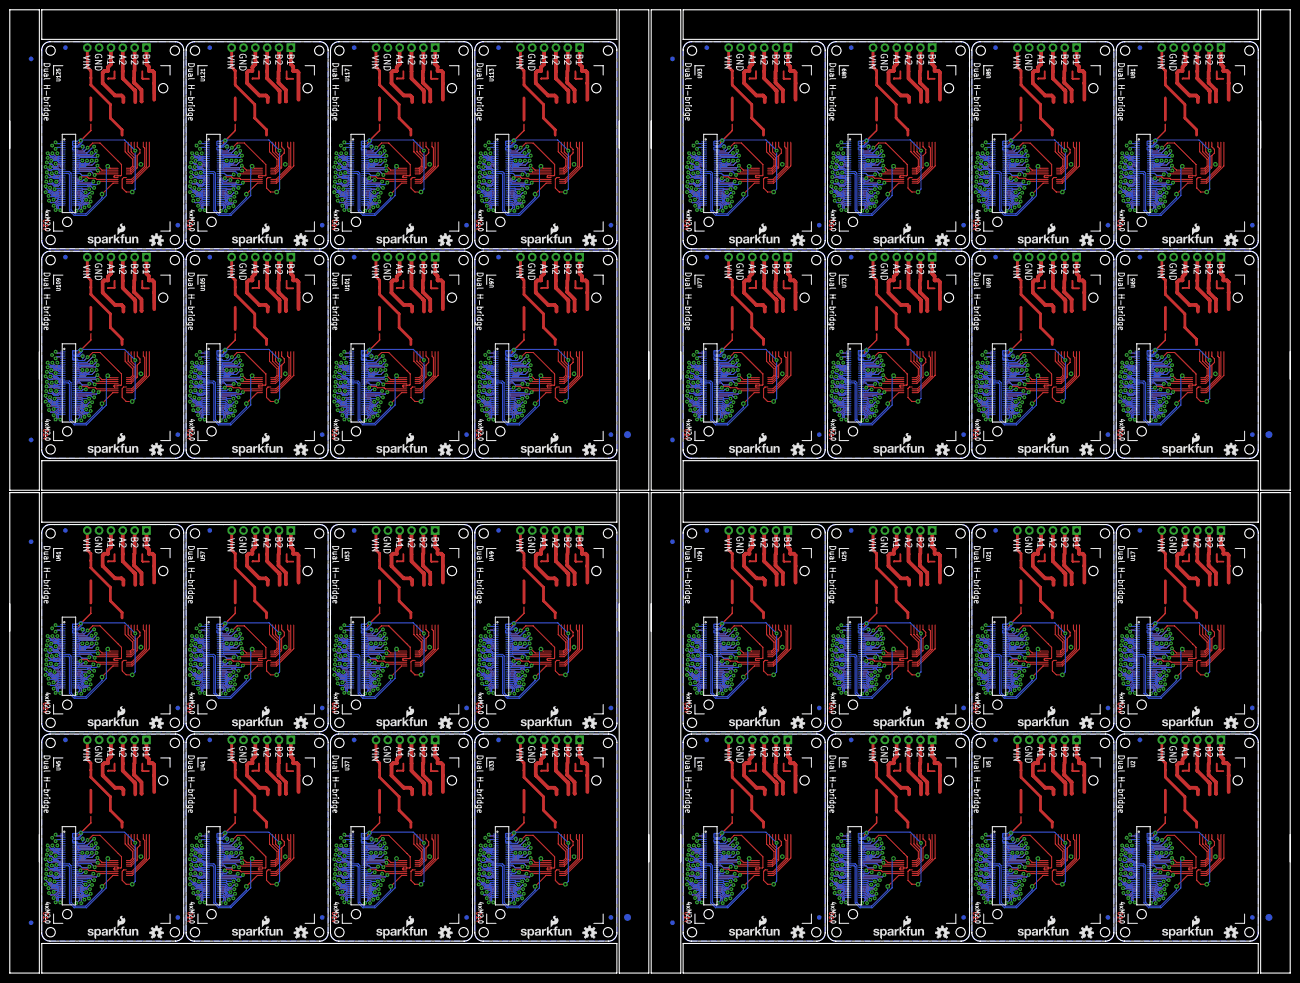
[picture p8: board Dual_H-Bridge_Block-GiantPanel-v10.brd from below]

Board: 2 copper layers, 274.8 x 206.8 mm, 824 parts (204 on the bottom side), 2336 nets.

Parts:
C1, C4, C7, C10, C13, C16, C19, C22, C25, C28, C31, C34, C37, C40, C43, C46, C49, C52, C55, C58, C61, C64, C67, C70, C73, C76, C79, C82, C85, C88, C91, C94: 10uF; EIA3216
C2, C3, C5, C6, C8, C9, C11, C12, C14, C15, C17, C18, C20, C21, C23, C24, C26, C27, C29, C30, C32, C33, C35, C36, C38, C39, C41, C42, C44, C45, C47, C48, C50, C51, C53, C54, C56, C57, C59, C60, C62, C63, C65, C66, C68, C69, C71, C72, C74, C75, C77, C78, C80, C81, C83, C84, C86, C87, C89, C90, C92, C93, C95, C96: 0.1uF; 0603-CAP
D1, D6, D11, D16, D21, D26, D31, D36, D41, D46, D51, D56, D61, D66, D71, D76, D81, D86, D91, D96, D101, D106, D111, D116, D121, D126, D131, D136, D141, D146, D151, D156: MBRA140; SMA-DIODE
D2, D3, D7, D8, D12, D13, D17, D18, D22, D23, D27, D28, D32, D33, D37, D38, D42, D43, D47, D48, D52, D53, D57, D58, D62, D63, D67, D68, D72, D73, D77, D78, D82, D83, D87, D88, D92, D93, D97, D98, D102, D103, D107, D108, D112, D113, D117, D118, D122, D123, D127, D128, D132, D133, D137, D138, D142, D143, D147, D148, D152, D153, D157, D158: GREEN; LED-0603
D4, D5, D9, D10, D14, D15, D19, D20, D24, D25, D29, D30, D34, D35, D39, D40, D44, D45, D49, D50, D54, D55, D59, D60, D64, D65, D69, D70, D74, D75, D79, D80, D84, D85, D89, D90, D94, D95, D99, D100, D104, D105, D109, D110, D114, D115, D119, D120, D124, D125, D129, D130, D134, D135, D139, D140, D144, D145, D149, D150, D154, D155, D159, D160: RED; LED-0603
E$1, E$2, E$11, E$12, E$17, E$18, E$23, E$24: FIDUCIAL-1.5X3
E$3, E$4, E$5, E$6, E$7, E$8, E$9, E$10, E$13, E$14, E$15, E$16, E$19, E$20, E$21, E$22: FIDUCIAL-1X2
FID1, FID2, FID3, FID4, FID5, FID6, FID7, FID8, FID9, FID10, FID11, FID12, FID13, FID14, FID15, FID16, FID17, FID18, FID19, FID20, FID21, FID22, FID23, FID24, FID25, FID26, FID27, FID28, FID29, FID30, FID31, FID32, FID33, FID34, FID35, FID36, FID37, FID38, FID39, FID40, FID41, FID42, FID43, FID44, FID45, FID46, FID47, FID48, FID49, FID50, FID51, FID52, FID53, FID54, FID55, FID56, FID57, FID58, FID59, FID60, FID61, FID62, FID63, FID64, FID65, FID66, FID67, FID68, FID69, FID70, FID71, FID72, FID73, FID74, FID75, FID76, FID77, FID78, FID79, FID80, FID81, FID82, FID83, FID84, FID85, FID86, FID87, FID88, FID89, FID90, FID91, FID92, FID93, FID94, FID95, FID96, FID97, FID98, FID99, FID100, FID101, FID102, FID103, FID104, FID105, FID106, FID107, FID108, FID109, FID110, FID111, FID112, FID113, FID114, FID115, FID116, FID117, FID118, FID119, FID120, FID121, FID122, FID123, FID124, FID125, FID126, FID127, FID128: FIDUCIAL1X2; FIDUCIAL-1X2
JP1, JP3, JP5, JP7, JP9, JP11, JP13, JP15, JP17, JP19, JP21, JP23, JP25, JP27, JP29, JP31, JP33, JP35, JP37, JP39, JP41, JP43, JP45, JP47, JP49, JP51, JP53, JP55, JP57, JP59, JP61, JP63: 1X04
JP2, JP4, JP6, JP8, JP10, JP12, JP14, JP16, JP18, JP20, JP22, JP24, JP26, JP28, JP30, JP32, JP34, JP36, JP38, JP40, JP42, JP44, JP46, JP48, JP50, JP52, JP54, JP56, JP58, JP60, JP62, JP64: M02PTH; 1X02
LOGO1, LOGO2, LOGO5, LOGO7, LOGO9, LOGO11, LOGO13, LOGO15, LOGO17, LOGO19, LOGO21, LOGO23, LOGO25, LOGO27, LOGO29, LOGO31, LOGO33, LOGO35, LOGO37, LOGO39, LOGO41, LOGO43, LOGO45, LOGO47, LOGO49, LOGO51, LOGO53, LOGO55, LOGO57, LOGO59, LOGO61, LOGO63, LOGO65, LOGO67, LOGO69, LOGO71, LOGO73, LOGO75, LOGO77, LOGO79, LOGO81, LOGO83, LOGO85, LOGO87, LOGO89, LOGO91, LOGO93, LOGO95, LOGO97, LOGO99, LOGO101, LOGO103, LOGO105, LOGO107, LOGO109, LOGO111, LOGO113, LOGO115, LOGO117, LOGO119, LOGO121, LOGO123, LOGO125, LOGO127: OSHW-LOGOS; OSHW-LOGO-S
LOGO3, LOGO4, LOGO6, LOGO8, LOGO10, LOGO12, LOGO14, LOGO16, LOGO18, LOGO20, LOGO22, LOGO24, LOGO26, LOGO28, LOGO30, LOGO32, LOGO34, LOGO36, LOGO38, LOGO40, LOGO42, LOGO44, LOGO46, LOGO48, LOGO50, LOGO52, LOGO54, LOGO56, LOGO58, LOGO60, LOGO62, LOGO64, LOGO66, LOGO68, LOGO70, LOGO72, LOGO74, LOGO76, LOGO78, LOGO80, LOGO82, LOGO84, LOGO86, LOGO88, LOGO90, LOGO92, LOGO94, LOGO96, LOGO98, LOGO100, LOGO102, LOGO104, LOGO106, LOGO108, LOGO110, LOGO112, LOGO114, LOGO116, LOGO118, LOGO120, LOGO122, LOGO124, LOGO126, LOGO128: SFE_LOGO_NAME_FLAME.1_INCH; SFE_LOGO_NAME_FLAME_.1
R1, R2, R3, R4, R5, R6, R7, R8, R9, R10, R11, R12, R13, R14, R15, R16, R17, R18, R19, R20, R21, R22, R23, R24, R25, R26, R27, R28, R29, R30, R31, R32, R33, R34, R35, R36, R37, R38, R39, R40, R41, R42, R43, R44, R45, R46, R47, R48, R49, R50, R51, R52, R53, R54, R55, R56, R57, R58, R59, R60, R61, R62, R63, R64: 680; 0603-RES
SJ1, SJ2, SJ3, SJ4, SJ5, SJ6, SJ7, SJ8, SJ9, SJ10, SJ11, SJ12, SJ13, SJ14, SJ15, SJ16, SJ17, SJ18, SJ19, SJ20, SJ21, SJ22, SJ23, SJ24, SJ25, SJ26, SJ27, SJ28, SJ29, SJ30, SJ31, SJ32: VSYS ENABLE; PAD-JUMPER-2-NO_YES_SILK
U1, U7, U11, U15, U19, U23, U27, U31, U35, U39, U43, U47, U51, U55, U59, U63, U67, U71, U75, U79, U83, U87, U91, U95, U99, U103, U107, U111, U115, U119, U123, U127: TB6612FNG; SSOP24
U2, U5, U9, U13, U17, U21, U25, U29, U33, U37, U41, U45, U49, U53, U57, U61, U65, U69, U73, U77, U81, U85, U89, U93, U97, U101, U105, U109, U113, U117, U121, U125: EDISON_CONNECTOR_FULLMOUNTING_HOLES; EDISON_DAUGHTER
U3, U6, U10, U14, U18, U22, U26, U30, U34, U38, U42, U46, U50, U54, U58, U62, U66, U70, U74, U78, U82, U86, U90, U94, U98, U102, U106, U110, U114, U118, U122, U126: EDISON_CONNECTOR_FULLHEADER; DF40C-70DP-0.4(51)
U4, U8, U12, U16, U20, U24, U28, U32, U36, U40, U44, U48, U52, U56, U60, U64, U68, U72, U76, U80, U84, U88, U92, U96, U100, U104, U108, U112, U116, U120, U124, U128: TXB0108; UFDFN-20

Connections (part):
1.8V: C3.1, U2.12, U3.12, U4.5, U4.6
1.8V1: C6.1, U5.12, U6.12, U8.5, U8.6
1.8V2: C9.1, U9.12, U10.12, U12.5, U12.6
1.8V3: C12.1, U13.12, U14.12, U16.5, U16.6
1.8V4: C15.1, U17.12, U18.12, U20.5, U20.6
1.8V5: C18.1, U21.12, U22.12, U24.5, U24.6
1.8V6: C21.1, U25.12, U26.12, U28.5, U28.6
1.8V7: C24.1, U29.12, U30.12, U32.5, U32.6
1.8V8: C27.1, U33.12, U34.12, U36.5, U36.6
1.8V9: C30.1, U37.12, U38.12, U40.5, U40.6
1.8V10: C33.1, U41.12, U42.12, U44.5, U44.6
1.8V11: C36.1, U45.12, U46.12, U48.5, U48.6
1.8V12: C39.1, U49.12, U50.12, U52.5, U52.6
1.8V13: C42.1, U53.12, U54.12, U56.5, U56.6
1.8V14: C45.1, U57.12, U58.12, U60.5, U60.6
1.8V15: C48.1, U61.12, U62.12, U64.5, U64.6
1.8V16: C51.1, U65.12, U66.12, U68.5, U68.6
1.8V17: C54.1, U69.12, U70.12, U72.5, U72.6
1.8V18: C57.1, U73.12, U74.12, U76.5, U76.6
1.8V19: C60.1, U77.12, U78.12, U80.5, U80.6
1.8V20: C63.1, U81.12, U82.12, U84.5, U84.6
1.8V21: C66.1, U85.12, U86.12, U88.5, U88.6
1.8V22: C69.1, U89.12, U90.12, U92.5, U92.6
1.8V23: C72.1, U93.12, U94.12, U96.5, U96.6
1.8V24: C75.1, U97.12, U98.12, U100.5, U100.6
1.8V25: C78.1, U101.12, U102.12, U104.5, U104.6
1.8V26: C81.1, U105.12, U106.12, U108.5, U108.6
1.8V27: C84.1, U109.12, U110.12, U112.5, U112.6
1.8V28: C87.1, U113.12, U114.12, U116.5, U116.6
1.8V29: C90.1, U117.12, U118.12, U120.5, U120.6
1.8V30: C93.1, U121.12, U122.12, U124.5, U124.6
1.8V31: C96.1, U125.12, U126.12, U128.5, U128.6
3.3V: U2.8, U2.10, U3.8, U3.10
3.3V1: U5.8, U5.10, U6.8, U6.10
3.3V2: U9.8, U9.10, U10.8, U10.10
3.3V3: U13.8, U13.10, U14.8, U14.10
3.3V4: U17.8, U17.10, U18.8, U18.10
3.3V5: U21.8, U21.10, U22.8, U22.10
3.3V6: U25.8, U25.10, U26.8, U26.10
3.3V7: U29.8, U29.10, U30.8, U30.10
3.3V8: U33.8, U33.10, U34.8, U34.10
3.3V9: U37.8, U37.10, U38.8, U38.10
3.3V10: U41.8, U41.10, U42.8, U42.10
3.3V11: U45.8, U45.10, U46.8, U46.10
3.3V12: U49.8, U49.10, U50.8, U50.10
3.3V13: U53.8, U53.10, U54.8, U54.10
3.3V14: U57.8, U57.10, U58.8, U58.10
3.3V15: U61.8, U61.10, U62.8, U62.10
3.3V16: U65.8, U65.10, U66.8, U66.10
3.3V17: U69.8, U69.10, U70.8, U70.10
3.3V18: U73.8, U73.10, U74.8, U74.10
3.3V19: U77.8, U77.10, U78.8, U78.10
3.3V20: U81.8, U81.10, U82.8, U82.10
3.3V21: U85.8, U85.10, U86.8, U86.10
3.3V22: U89.8, U89.10, U90.8, U90.10
3.3V23: U93.8, U93.10, U94.8, U94.10
3.3V24: U97.8, U97.10, U98.8, U98.10
3.3V25: U101.8, U101.10, U102.8, U102.10
3.3V26: U105.8, U105.10, U106.8, U106.10
3.3V27: U109.8, U109.10, U110.8, U110.10
3.3V28: U113.8, U113.10, U114.8, U114.10
3.3V29: U117.8, U117.10, U118.8, U118.10
3.3V30: U121.8, U121.10, U122.8, U122.10
3.3V31: U125.8, U125.10, U126.8, U126.10
A1: JP1.4, R1.2, U1.1, U1.2
A2: D3.C, D5.A, JP1.3, U1.5, U1.6
A3: D8.C, D10.A, JP3.3, U7.5, U7.6
A4: JP3.4, R3.2, U7.1, U7.2
A5: D13.C, D15.A, JP5.3, U11.5, U11.6
A6: JP5.4, R5.2, U11.1, U11.2
A7: D18.C, D20.A, JP7.3, U15.5, U15.6
A8: JP7.4, R7.2, U15.1, U15.2
A9: D23.C, D25.A, JP9.3, U19.5, U19.6
A10: JP9.4, R9.2, U19.1, U19.2
A11: D28.C, D30.A, JP11.3, U23.5, U23.6
A12: JP11.4, R11.2, U23.1, U23.2
A13: D33.C, D35.A, JP13.3, U27.5, U27.6
A14: JP13.4, R13.2, U27.1, U27.2
A15: D38.C, D40.A, JP15.3, U31.5, U31.6
A16: JP15.4, R15.2, U31.1, U31.2
A17: D43.C, D45.A, JP17.3, U35.5, U35.6
A18: JP17.4, R17.2, U35.1, U35.2
A19: D48.C, D50.A, JP19.3, U39.5, U39.6
A20: JP19.4, R19.2, U39.1, U39.2
A21: D53.C, D55.A, JP21.3, U43.5, U43.6
A22: JP21.4, R21.2, U43.1, U43.2
A23: D58.C, D60.A, JP23.3, U47.5, U47.6
A24: JP23.4, R23.2, U47.1, U47.2
A25: D63.C, D65.A, JP25.3, U51.5, U51.6
A26: JP25.4, R25.2, U51.1, U51.2
A27: D68.C, D70.A, JP27.3, U55.5, U55.6
A28: JP27.4, R27.2, U55.1, U55.2
A29: D73.C, D75.A, JP29.3, U59.5, U59.6
A30: JP29.4, R29.2, U59.1, U59.2
A31: D78.C, D80.A, JP31.3, U63.5, U63.6
A32: JP31.4, R31.2, U63.1, U63.2
A33: D83.C, D85.A, JP33.3, U67.5, U67.6
A34: JP33.4, R33.2, U67.1, U67.2
A35: D88.C, D90.A, JP35.3, U71.5, U71.6
A36: JP35.4, R35.2, U71.1, U71.2
A37: D93.C, D95.A, JP37.3, U75.5, U75.6
A38: JP37.4, R37.2, U75.1, U75.2
A39: D98.C, D100.A, JP39.3, U79.5, U79.6
A40: JP39.4, R39.2, U79.1, U79.2
A41: D103.C, D105.A, JP41.3, U83.5, U83.6
A42: JP41.4, R41.2, U83.1, U83.2
A43: D108.C, D110.A, JP43.3, U87.5, U87.6
A44: JP43.4, R43.2, U87.1, U87.2
A45: D113.C, D115.A, JP45.3, U91.5, U91.6
A46: JP45.4, R45.2, U91.1, U91.2
A47: D118.C, D120.A, JP47.3, U95.5, U95.6
A48: JP47.4, R47.2, U95.1, U95.2
A49: D123.C, D125.A, JP49.3, U99.5, U99.6
A50: JP49.4, R49.2, U99.1, U99.2
A51: D128.C, D130.A, JP51.3, U103.5, U103.6
A52: JP51.4, R51.2, U103.1, U103.2
A53: D133.C, D135.A, JP53.3, U107.5, U107.6
A54: JP53.4, R53.2, U107.1, U107.2
A55: D138.C, D140.A, JP55.3, U111.5, U111.6
A56: JP55.4, R55.2, U111.1, U111.2
A57: D143.C, D145.A, JP57.3, U115.5, U115.6
A58: JP57.4, R57.2, U115.1, U115.2
A59: D148.C, D150.A, JP59.3, U119.5, U119.6
A60: JP59.4, R59.2, U119.1, U119.2
A61: D153.C, D155.A, JP61.3, U123.5, U123.6
A62: JP61.4, R61.2, U123.1, U123.2
A63: D158.C, D160.A, JP63.3, U127.5, U127.6
A64: JP63.4, R63.2, U127.1, U127.2
B1: JP1.1, R2.2, U1.11, U1.12
B2: D2.C, D4.A, JP1.2, U1.7, U1.8
B3: JP3.1, R4.2, U7.11, U7.12
B4: D7.C, D9.A, JP3.2, U7.7, U7.8
B5: JP5.1, R6.2, U11.11, U11.12
B6: D12.C, D14.A, JP5.2, U11.7, U11.8
B7: JP7.1, R8.2, U15.11, U15.12
B8: D17.C, D19.A, JP7.2, U15.7, U15.8
B9: JP9.1, R10.2, U19.11, U19.12
B10: D22.C, D24.A, JP9.2, U19.7, U19.8
B11: JP11.1, R12.2, U23.11, U23.12
B12: D27.C, D29.A, JP11.2, U23.7, U23.8
B13: JP13.1, R14.2, U27.11, U27.12
B14: D32.C, D34.A, JP13.2, U27.7, U27.8
B15: JP15.1, R16.2, U31.11, U31.12
B16: D37.C, D39.A, JP15.2, U31.7, U31.8
B17: JP17.1, R18.2, U35.11, U35.12
B18: D42.C, D44.A, JP17.2, U35.7, U35.8
B19: JP19.1, R20.2, U39.11, U39.12
B20: D47.C, D49.A, JP19.2, U39.7, U39.8
B21: JP21.1, R22.2, U43.11, U43.12
B22: D52.C, D54.A, JP21.2, U43.7, U43.8
B23: JP23.1, R24.2, U47.11, U47.12
B24: D57.C, D59.A, JP23.2, U47.7, U47.8
B25: JP25.1, R26.2, U51.11, U51.12
B26: D62.C, D64.A, JP25.2, U51.7, U51.8
B27: JP27.1, R28.2, U55.11, U55.12
B28: D67.C, D69.A, JP27.2, U55.7, U55.8
B29: JP29.1, R30.2, U59.11, U59.12
B30: D72.C, D74.A, JP29.2, U59.7, U59.8
B31: JP31.1, R32.2, U63.11, U63.12
B32: D77.C, D79.A, JP31.2, U63.7, U63.8
B33: JP33.1, R34.2, U67.11, U67.12
B34: D82.C, D84.A, JP33.2, U67.7, U67.8
B35: JP35.1, R36.2, U71.11, U71.12
B36: D87.C, D89.A, JP35.2, U71.7, U71.8
B37: JP37.1, R38.2, U75.11, U75.12
B38: D92.C, D94.A, JP37.2, U75.7, U75.8
B39: JP39.1, R40.2, U79.11, U79.12
B40: D97.C, D99.A, JP39.2, U79.7, U79.8
B41: JP41.1, R42.2, U83.11, U83.12
B42: D102.C, D104.A, JP41.2, U83.7, U83.8
B43: JP43.1, R44.2, U87.11, U87.12
B44: D107.C, D109.A, JP43.2, U87.7, U87.8
B45: JP45.1, R46.2, U91.11, U91.12
B46: D112.C, D114.A, JP45.2, U91.7, U91.8
B47: JP47.1, R48.2, U95.11, U95.12
B48: D117.C, D119.A, JP47.2, U95.7, U95.8
B49: JP49.1, R50.2, U99.11, U99.12
B50: D122.C, D124.A, JP49.2, U99.7, U99.8
B51: JP51.1, R52.2, U103.11, U103.12
B52: D127.C, D129.A, JP51.2, U103.7, U103.8
B53: JP53.1, R54.2, U107.11, U107.12
B54: D132.C, D134.A, JP53.2, U107.7, U107.8
B55: JP55.1, R56.2, U111.11, U111.12
B56: D137.C, D139.A, JP55.2, U111.7, U111.8
B57: JP57.1, R58.2, U115.11, U115.12
B58: D142.C, D144.A, JP57.2, U115.7, U115.8
B59: JP59.1, R60.2, U119.11, U119.12
B60: D147.C, D149.A, JP59.2, U119.7, U119.8
B61: JP61.1, R62.2, U123.11, U123.12
B62: D152.C, D154.A, JP61.2, U123.7, U123.8
B63: JP63.1, R64.2, U127.11, U127.12
B64: D157.C, D159.A, JP63.2, U127.7, U127.8
DCIN: U2.14, U3.14
DCIN1: U5.14, U6.14
DCIN2: U9.14, U10.14
DCIN3: U13.14, U14.14
DCIN4: U17.14, U18.14
DCIN5: U21.14, U22.14
DCIN6: U25.14, U26.14
DCIN7: U29.14, U30.14
DCIN8: U33.14, U34.14
DCIN9: U37.14, U38.14
DCIN10: U41.14, U42.14
DCIN11: U45.14, U46.14
DCIN12: U49.14, U50.14
DCIN13: U53.14, U54.14
DCIN14: U57.14, U58.14
DCIN15: U61.14, U62.14
DCIN16: U65.14, U66.14
DCIN17: U69.14, U70.14
DCIN18: U73.14, U74.14
DCIN19: U77.14, U78.14
DCIN20: U81.14, U82.14
DCIN21: U85.14, U86.14
DCIN22: U89.14, U90.14
DCIN23: U93.14, U94.14
DCIN24: U97.14, U98.14
DCIN25: U101.14, U102.14
DCIN26: U105.14, U106.14
DCIN27: U109.14, U110.14
DCIN28: U113.14, U114.14
DCIN29: U117.14, U118.14
DCIN30: U121.14, U122.14
DCIN31: U125.14, U126.14
FAULT: U2.19, U3.19
FAULT1: U5.19, U6.19
FAULT2: U9.19, U10.19
FAULT3: U13.19, U14.19
FAULT4: U17.19, U18.19
FAULT5: U21.19, U22.19
FAULT6: U25.19, U26.19
FAULT7: U29.19, U30.19
FAULT8: U33.19, U34.19
FAULT9: U37.19, U38.19
FAULT10: U41.19, U42.19
FAULT11: U45.19, U46.19
FAULT12: U49.19, U50.19
FAULT13: U53.19, U54.19
FAULT14: U57.19, U58.19
FAULT15: U61.19, U62.19
FAULT16: U65.19, U66.19
FAULT17: U69.19, U70.19
FAULT18: U73.19, U74.19
FAULT19: U77.19, U78.19
FAULT20: U81.19, U82.19
FAULT21: U85.19, U86.19
FAULT22: U89.19, U90.19
FAULT23: U93.19, U94.19
FAULT24: U97.19, U98.19
FAULT25: U101.19, U102.19
FAULT26: U105.19, U106.19
FAULT27: U109.19, U110.19
FAULT28: U113.19, U114.19
FAULT29: U117.19, U118.19
FAULT30: U121.19, U122.19
FAULT31: U125.19, U126.19
FW_RCVR: U2.69, U3.69
FW_RCVR1: U5.69, U6.69
FW_RCVR2: U9.69, U10.69
FW_RCVR3: U13.69, U14.69
FW_RCVR4: U17.69, U18.69
FW_RCVR5: U21.69, U22.69
FW_RCVR6: U25.69, U26.69
FW_RCVR7: U29.69, U30.69
FW_RCVR8: U33.69, U34.69
FW_RCVR9: U37.69, U38.69
FW_RCVR10: U41.69, U42.69
FW_RCVR11: U45.69, U46.69
FW_RCVR12: U49.69, U50.69
FW_RCVR13: U53.69, U54.69
FW_RCVR14: U57.69, U58.69
FW_RCVR15: U61.69, U62.69
FW_RCVR16: U65.69, U66.69
FW_RCVR17: U69.69, U70.69
FW_RCVR18: U73.69, U74.69
FW_RCVR19: U77.69, U78.69
FW_RCVR20: U81.69, U82.69
FW_RCVR21: U85.69, U86.69
FW_RCVR22: U89.69, U90.69
FW_RCVR23: U93.69, U94.69
FW_RCVR24: U97.69, U98.69
FW_RCVR25: U101.69, U102.69
FW_RCVR26: U105.69, U106.69
FW_RCVR27: U109.69, U110.69
FW_RCVR28: U113.69, U114.69
FW_RCVR29: U117.69, U118.69
FW_RCVR30: U121.69, U122.69
FW_RCVR31: U125.69, U126.69
GND: C1.C, C2.2, C3.2, JP2.1, U1.3, U1.4, U1.9, U1.10, U1.18, U2.1, U2.5, U2.9, U2.11, U2.13, U2.15, U3.1, U3.5, U3.9, U3.11, U3.13, U3.15, U4.15
GND1: C4.C, C5.2, C6.2, JP4.1, U5.1, U5.5, U5.9, U5.11, U5.13, U5.15, U6.1, U6.5, U6.9, U6.11, U6.13, U6.15, U7.3, U7.4, U7.9, U7.10, U7.18, U8.15
GND2: C7.C, C8.2, C9.2, JP6.1, U9.1, U9.5, U9.9, U9.11, U9.13, U9.15, U10.1, U10.5, U10.9, U10.11, U10.13, U10.15, U11.3, U11.4, U11.9, U11.10, U11.18, U12.15
GND3: C10.C, C11.2, C12.2, JP8.1, U13.1, U13.5, U13.9, U13.11, U13.13, U13.15, U14.1, U14.5, U14.9, U14.11, U14.13, U14.15, U15.3, U15.4, U15.9, U15.10, U15.18, U16.15
GND4: C13.C, C14.2, C15.2, JP10.1, U17.1, U17.5, U17.9, U17.11, U17.13, U17.15, U18.1, U18.5, U18.9, U18.11, U18.13, U18.15, U19.3, U19.4, U19.9, U19.10, U19.18, U20.15
GND5: C16.C, C17.2, C18.2, JP12.1, U21.1, U21.5, U21.9, U21.11, U21.13, U21.15, U22.1, U22.5, U22.9, U22.11, U22.13, U22.15, U23.3, U23.4, U23.9, U23.10, U23.18, U24.15
GND6: C19.C, C20.2, C21.2, JP14.1, U25.1, U25.5, U25.9, U25.11, U25.13, U25.15, U26.1, U26.5, U26.9, U26.11, U26.13, U26.15, U27.3, U27.4, U27.9, U27.10, U27.18, U28.15
GND7: C22.C, C23.2, C24.2, JP16.1, U29.1, U29.5, U29.9, U29.11, U29.13, U29.15, U30.1, U30.5, U30.9, U30.11, U30.13, U30.15, U31.3, U31.4, U31.9, U31.10, U31.18, U32.15
GND8: C25.C, C26.2, C27.2, JP18.1, U33.1, U33.5, U33.9, U33.11, U33.13, U33.15, U34.1, U34.5, U34.9, U34.11, U34.13, U34.15, U35.3, U35.4, U35.9, U35.10, U35.18, U36.15
GND9: C28.C, C29.2, C30.2, JP20.1, U37.1, U37.5, U37.9, U37.11, U37.13, U37.15, U38.1, U38.5, U38.9, U38.11, U38.13, U38.15, U39.3, U39.4, U39.9, U39.10, U39.18, U40.15
GND10: C31.C, C32.2, C33.2, JP22.1, U41.1, U41.5, U41.9, U41.11, U41.13, U41.15, U42.1, U42.5, U42.9, U42.11, U42.13, U42.15, U43.3, U43.4, U43.9, U43.10, U43.18, U44.15
GND11: C34.C, C35.2, C36.2, JP24.1, U45.1, U45.5, U45.9, U45.11, U45.13, U45.15, U46.1, U46.5, U46.9, U46.11, U46.13, U46.15, U47.3, U47.4, U47.9, U47.10, U47.18, U48.15
GND12: C37.C, C38.2, C39.2, JP26.1, U49.1, U49.5, U49.9, U49.11, U49.13, U49.15, U50.1, U50.5, U50.9, U50.11, U50.13, U50.15, U51.3, U51.4, U51.9, U51.10, U51.18, U52.15
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

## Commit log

2014-08-12 initial commit with completed layout, Ready for review
    [Mezzanine_Dual_H-Bridge.brd, Mezzanine_Dual_H-Bridge.sch]
2014-08-12 removed Edzzanine from name
    [Mezzanine_Dual_H-Bridge.brd]
2014-08-14 fixed OE high
    [Mezzanine_Dual_H-Bridge.brd, Mezzanine_Dual_H-Bridge.sch]
2014-09-22 Added LED's for motor direction Added Diode Jumper circuit to enable VSYS to power VIN Corrected Name and location Removed extra dimensions and cleaned up drawing Added DCIN pin and completed circuit.
    [Mezzanine_Dual_H-Bridge.brd, Mezzanine_Dual_H-Bridge.sch]
2014-09-22 corrected labels
    [Mezzanine_Dual_H-Bridge.brd, Mezzanine_Dual_H-Bridge.sch]
2014-09-23 changed names of files
    [Dual_H-Bridge_Block.brd, Dual_H-Bridge_Block.sch]
2014-09-25 file cleanup
    [Dual_H-Bridge_Block.brd, Dual_H-Bridge_Block.sch]
2014-10-17 corrected package footprint to remove bridging.
    [Dual_H-Bridge_Block.brd, Dual_H-Bridge_Block.sch]
2014-10-17 fixed text to vector
    [Dual_H-Bridge_Block.brd]
2014-10-17 fixed pours
    [Dual_H-Bridge_Block.brd]
2014-10-17 fixed level shifter pad jumper
    [Dual_H-Bridge_Block.brd]
2014-10-17 Changed Logic to vsys from vin
    [Dual_H-Bridge_Block.brd, Dual_H-Bridge_Block.sch]
2014-10-17 finishing routing and cleaning up pads
    [Dual_H-Bridge_Block.brd, Dual_H-Bridge_Block.sch]
2014-10-17 Ready for reds. Change LED resistors to 680 ohm Thicken traces of drive Touch up schematic No known to-do items
    [Dual_H-Bridge_Block.brd, Dual_H-Bridge_Block.sch]
2014-10-22 created v10 panels
    [Dual_H-Bridge_Block-GiantPanel-v10.brd, Dual_H-Bridge_Block-Panel-v10.brd]

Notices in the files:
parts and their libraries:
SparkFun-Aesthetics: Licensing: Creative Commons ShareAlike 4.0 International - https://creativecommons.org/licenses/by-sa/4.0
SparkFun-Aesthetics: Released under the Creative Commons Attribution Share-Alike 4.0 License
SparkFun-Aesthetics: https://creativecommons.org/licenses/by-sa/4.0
